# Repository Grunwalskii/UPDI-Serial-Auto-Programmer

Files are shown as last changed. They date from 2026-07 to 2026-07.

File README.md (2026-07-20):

# UPDI Serial Auto Programmer

A hardware tool that automatically switches between standard UART serial communication and UPDI programming modes using USB RTS control, featuring a CH340E bridge and integrated RS2228 analog multiplexer.

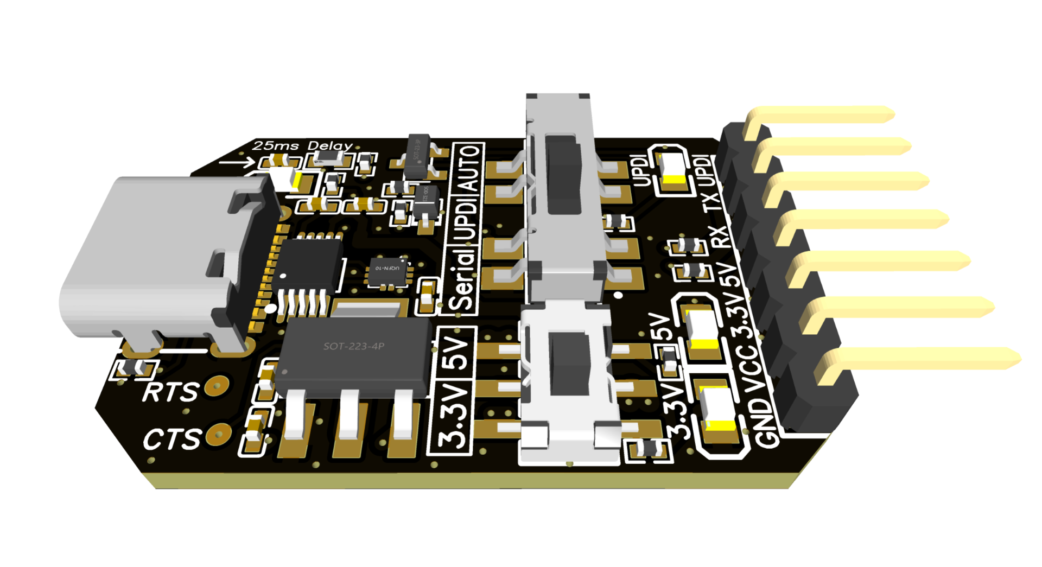
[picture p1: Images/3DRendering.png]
Rendering


## 🔌 Project Overview

This repository contains the design files for the **UPDI Serial Auto Programmer**, a highly integrated development tool designed for modern AVR microcontrollers (such as ATtiny 0/1/2-series, ATmega 0-series, and AVR Dx/Ex families). 

Unlike standard UPDI programmers that require physical jumpers or manual swapping between programming and serial monitoring modes, this board features an **automatic multiplexing circuit**. By utilizing the USB UART's **RTS (Request to Send)** line, the programmer dynamically switches between standard full-duplex UART serial communication and single-wire UPDI programming.

---

## 🛠️ Hardware Architecture & Features

### 1. USB & UART Core
* **USB Interface:** Standard **USB Type-C** (16-pin) connector configured with proper $5.1	{ k}\Omega$ pull-down resistors (`USB_R1`, `USB_R2`) on the CC lines for wide compatibility with host devices.
* **USB-to-UART Bridge:** Powered by the compact **CH340E** IC, ensuring excellent cross-platform driver compatibility and reliable high-baud-rate communication.

### 2. Auto-Switching Circuitry
* **High-Speed Multiplexer:** An **RS2228XUTQK10** dual SPDT analog switch (`U7`) acts as the core multiplexing engine.
* **RTS Control:** The `RTS` signal from the CH340E manages the multiplexer's control pin (`OE#`/`S`). 
  * **High / Default (Serial Monitor Mode):** Routes standard full-duplex `TXD` and `RXD` to the target header.
  * **Low (UPDI Programming Mode):** Couples the lines through a protective diode and resistor network (`1N5819WS` and $470\,\Omega$ / $1	ext{ k}\Omega$ resistors) to interface with the target's single-wire UPDI line automatically.
* **Timing Network:** An RC filter configuration ($120	ext{ k}\Omega$, $5.1	ext{ k}\Omega$, and $100	ext{ nF}$) conditions the `RTS` logic line transition profile (Rise time to $1.6	ext{ V}  pprox 4.51	ext{ ms}$; Fall time to $0.5	ext{ V}  pprox 25	ext{ ms}$).

### 3. Power Management
* **Dual Voltage Support:** Features a **AMS1117-3.3** Low Dropout (LDO) linear regulator to derive a stable 3.3V rail from the 5V USB bus line, supported by $10\,\mu	ext{F}$ filtering capacitors.
* **Rail Selection:** An `MS-22D28-G020` DPDT slide switch allows seamless manual switching between 5V and 3.3V power routing to the target.
* **Status LEDs:**
  * **Red LED:** Indicates the system is actively operating on the 5V rail.
  * **Green LED:** Indicates the system is operating on the 3.3V rail.

### 4. Target Interface Connectors
The output interface exposes a 7-pin header (`X6511WR-07H`) breaking out all necessary signals for the target board:
1. `GND`
2. `VCC` (Selected via slide switch)
3. `3.3V` (Direct output)
4. `5V` (Direct output)
5. `RXD`
6. `TXD`
7. `UPDI`

---

## 🚀 How It Works

1. **Standard Operation:** During normal terminal operations or debugging, `RTS` remains high. The analog switch links the target directly to the CH340E's hardware TX/RX lines for bidirectional serial printing.
2. **Programming Trigger:** When your programming tool chain (e.g., `pymcuprog` or `avrdude`) initiates a connection, it drops the `RTS` line low. 
3. **Automated Handoff:** The analog switch instantly redirects the TX/RX paths into the shared, bi-directional single-wire UPDI configuration required by the modern AVR architecture. 
4. **Post-Flash Restoration:** As soon as programming concludes and the software releases the port, `RTS` toggles back, re-enabling the transparent serial terminal mode instantly without resetting your hardware layout manually.
   
⚠️ **Hardware Dependency:** The automatic switching relies on the USB-UART chip's **RTS pin** toggling states; the programming IDE must support switching this line. The **Arduino IDE (via megaTinyCore)** handles this natively, whereas tools like PlatformIO or raw avrdude command lines may require custom upload flags to toggle the RTS line properly.

## Support

If you enjoy this project and want to support its development, you can buy me a coffee:



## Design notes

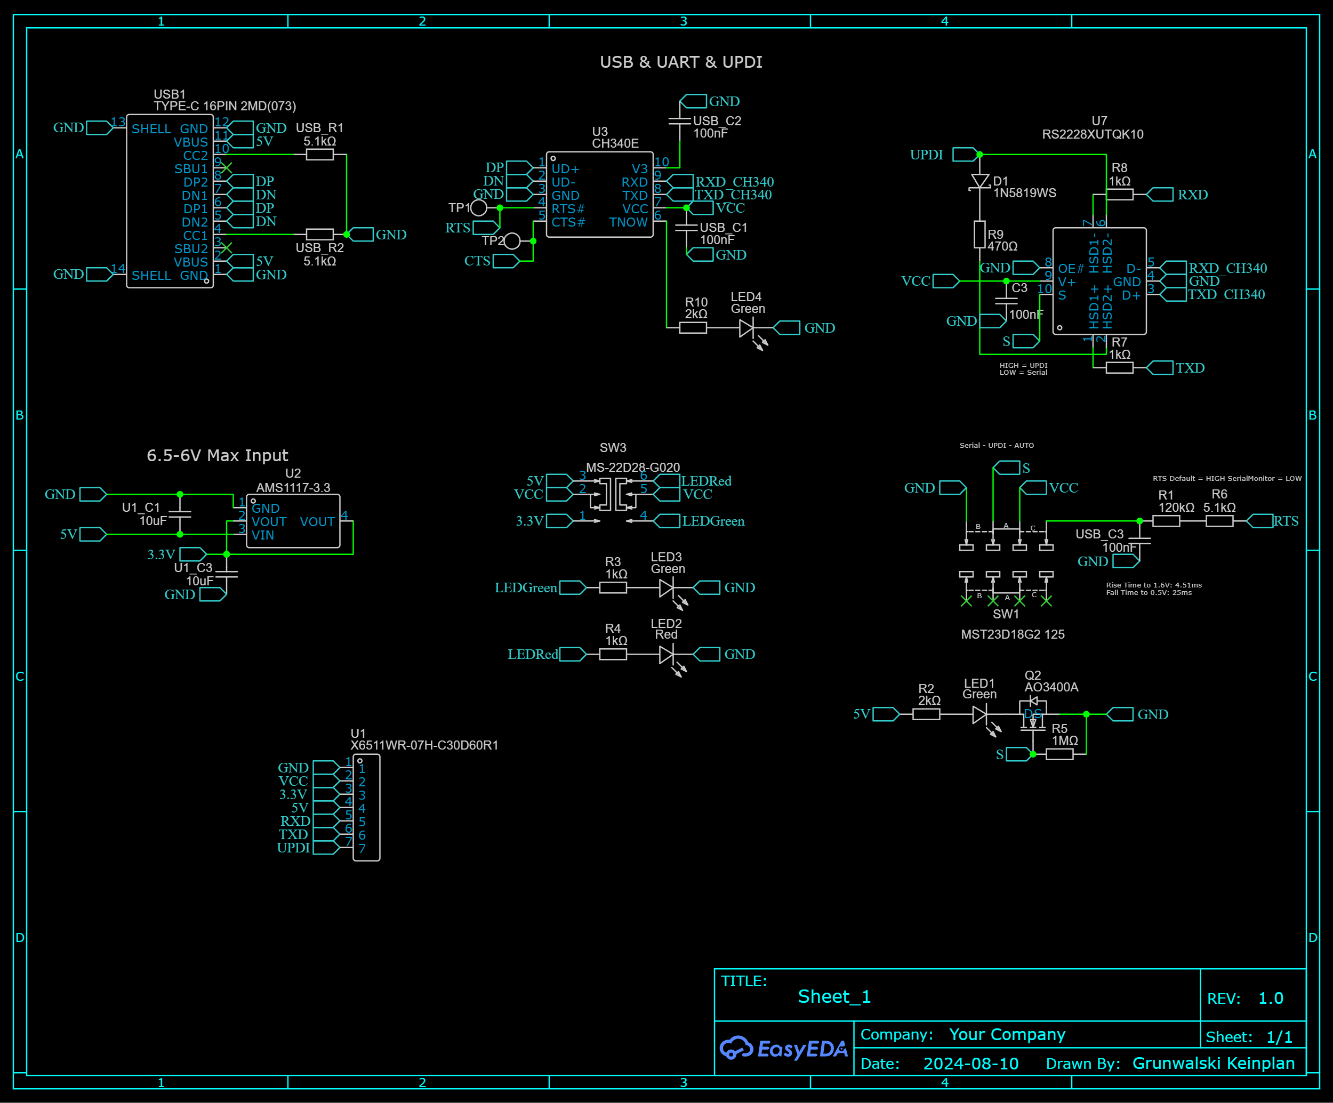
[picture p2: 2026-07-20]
Images/Schematic.png

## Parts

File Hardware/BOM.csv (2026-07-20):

ID | Name | Designator | Footprint | Quantity | Manufacturer Part | Manufacturer | Supplier | Supplier Part | Price
1 | X6511WR-07H-C30D60R1 | U1 | HDR-TH_7P-P2.54-H-M-W7.7-P | 1 | X6511WR-07H-C60D30R1 | XKB Connection(中国星坤) | LCSC | C2883845 | 0.266
2 | TESTPOINT | TP1,TP2 | TEST_TESTPOINT | 2
3 | 120kΩ | R1 | R0603 | 1 | 0603WAF1203T5E | UNI-ROYAL(厚声) | LCSC | C25808 | 0.003
4 | 100nF | USB_C3,C3,USB_C1,USB_C2 | C0402 | 4 | CL05B104KO5NNNC | SAMSUNG(三星) | LCSC | C1525 | 0.005
5 | 5.1kΩ | R6,USB_R1,USB_R2 | R0402 | 3 | 0402WGF5101TCE | UNI-ROYAL(厚声) | LCSC | C25905 | 0.001
6 | 2kΩ | R10,R2 | R0402 | 2 | 0402WGF2001TCE | UNI-ROYAL(厚声) | LCSC | C4109 | 0.006
7 | 1N5819WS | D1 | SOD-323_L1.8-W1.3-LS2.5-RD | 1 | 1N5819WS | Hottech(合科泰) | LCSC | C191023 | 0.014
8 | 470Ω | R9 | R0402 | 1 | 0402WGF4700TCE | UNI-ROYAL(厚声) | LCSC | C25117 | 0.007
9 | 1kΩ | R7,R8,R3,R4 | R0402 | 4 | 0402WGF1001TCE | UNI-ROYAL(厚声) | LCSC | C11702 | 0.008
10 | Green | LED4,LED3,LED1 | LED0805-R-RD | 3 | KT-0805G | KENTO | LCSC | C2297 | 0.016
11 | Red | LED2 | LED0805-R-RD | 1 | NCD0805R1 | 国星光电 | LCSC | C84256 | 0.013
12 | AO3400A | Q2 | SOT-23-3_L2.9-W1.3-P1.90-LS2.4-BR | 1 | AO3400A | AOS | LCSC | C20917 | 0.085
13 | 1MΩ | R5 | R0402 | 1 | 0402WGF1004TCE | UNI-ROYAL(厚声) | LCSC | C26083 | 0.007
14 | MST23D18G2 125 | SW1 | SW-SMD_SHOU_MST23D18G2 | 1 | MST23D18G2 125 | SHOU HAN(首韩) | LCSC | C2906281 | 0.068
15 | MS-22D28-G020 | SW3 | SW-SMD_MS-22D28-G020 | 1 | MS-22D28-G020 | G-Switch(品赞) | LCSC | C963205 | 0.123
16 | 10uF | U1_C1,U1_C3 | C0402 | 2 | CL05A106MQ5NUNC | SAMSUNG(三星) | LCSC | C15525 | 0.041
17 | AMS1117-3.3 | U2 | SOT-223-3_L6.5-W3.4-P2.30-LS7.0-BR | 1 | AMS1117-3.3 | AMS | LCSC | C6186 | 0.2
18 | RS2228XUTQK10 | U7 | WQFN-10_L1.8-W1.4-P0.40-BL | 1 | RS2228XUTQK10 | RUNIC(润石) | LCSC | C255479 | 0.306
19 | CH340E | U3 | MSOP-10_L3.0-W3.0-P0.50-LS5.0-BL | 1 | CH340E | WCH(南京沁恒) | LCSC | C99652 | 0.745
20 | TYPE-C 16PIN 2MD(073) | USB1 | USB-C-SMD_TYPE-C-6PIN-2MD-073 | 1 | TYPE-C 16PIN 2MD(073) | SHOU HAN(首韩) | LCSC | C2765186 | 0.074
